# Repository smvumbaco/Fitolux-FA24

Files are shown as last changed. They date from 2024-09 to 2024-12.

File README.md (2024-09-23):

MAKE SURE TO SUBMIT A PULL REQUEST BEFORE EACH BREAKING MERGE

# <PROJECT NAME>
<ADD BLURB ABOUT PROJECT>

## Directory Structure:
```
.
|
|───production  # contains files needed for final prototype
|   |
|   |───eCAD    # contains the KiCAD project
|   └───src     # contains the code needed for deployment
|
|───testing     # contains files relevant to testing components
|
└───README.md   # this file!
```

## Preferred Tools
- KiCAD for PCB development
- Visual Studio Code / PlatformIO for code development
- Git CLI / GitHub Desktop for managing Git

## Branches
> To isolate conflicts for schematics and code, we use two branches to actually develop off of depending on discipline
- `develop/ecad` is for schematic development, please create PR's into this branch for schematics and operate in this branch for layout
- `develop/src` is for code development, please create PR's into this branch for features

## References
- Schematics + Components (WIP)

## Practice Good Git Hygiene!
1. Only commit files you intended to change
2. Create branches for each feature, and larger branches for each development effort (i.e. ```develop/*```)
3. Check your branch before starting work
4. Pull frequently to avoid conflicts
5. Make Pull Requests when you are ready to merge into a larger branch

## Git Resources

* [Setting up Git](https://fanatical-colossus-434.notion.site/Git-Installation-and-Setup-d07b7d1ab5544424876f9fd3b4a0b312)
* [Intro to Git Crash Course](https://fanatical-colossus-434.notion.site/Crash-Course-Intro-to-Git-809641611da9478b8f9cca8fd97e49fe)

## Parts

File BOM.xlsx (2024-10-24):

Component | Package size | Value with unit | Link (JLCPCB)
Resistor | 403 | 10 ohms | Example

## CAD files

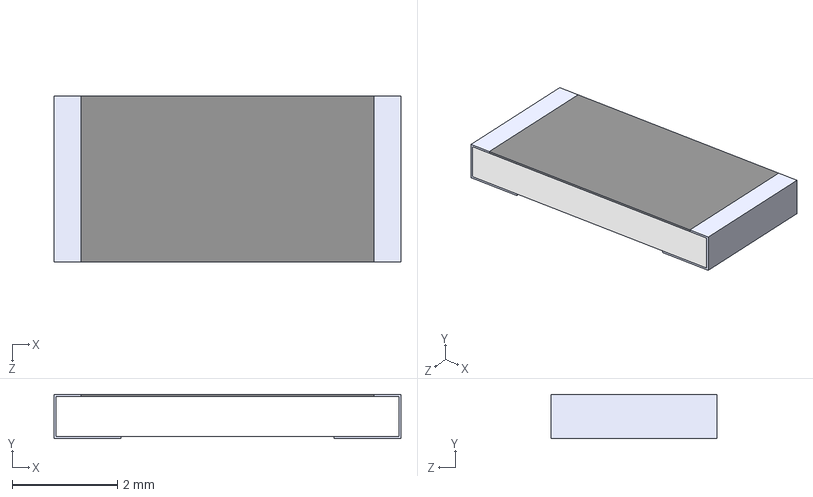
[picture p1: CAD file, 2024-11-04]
production/ecad/components/cad/R2_30k.step
6.58 x 0.84 x 3.15 mm

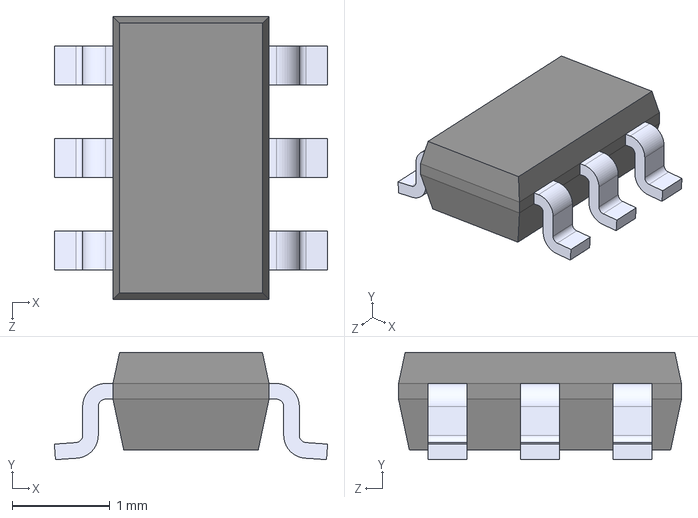
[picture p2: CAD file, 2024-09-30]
production/ecad/components/cad/TPS56339DDCR.step
2.80 x 1.10 x 2.90 mm

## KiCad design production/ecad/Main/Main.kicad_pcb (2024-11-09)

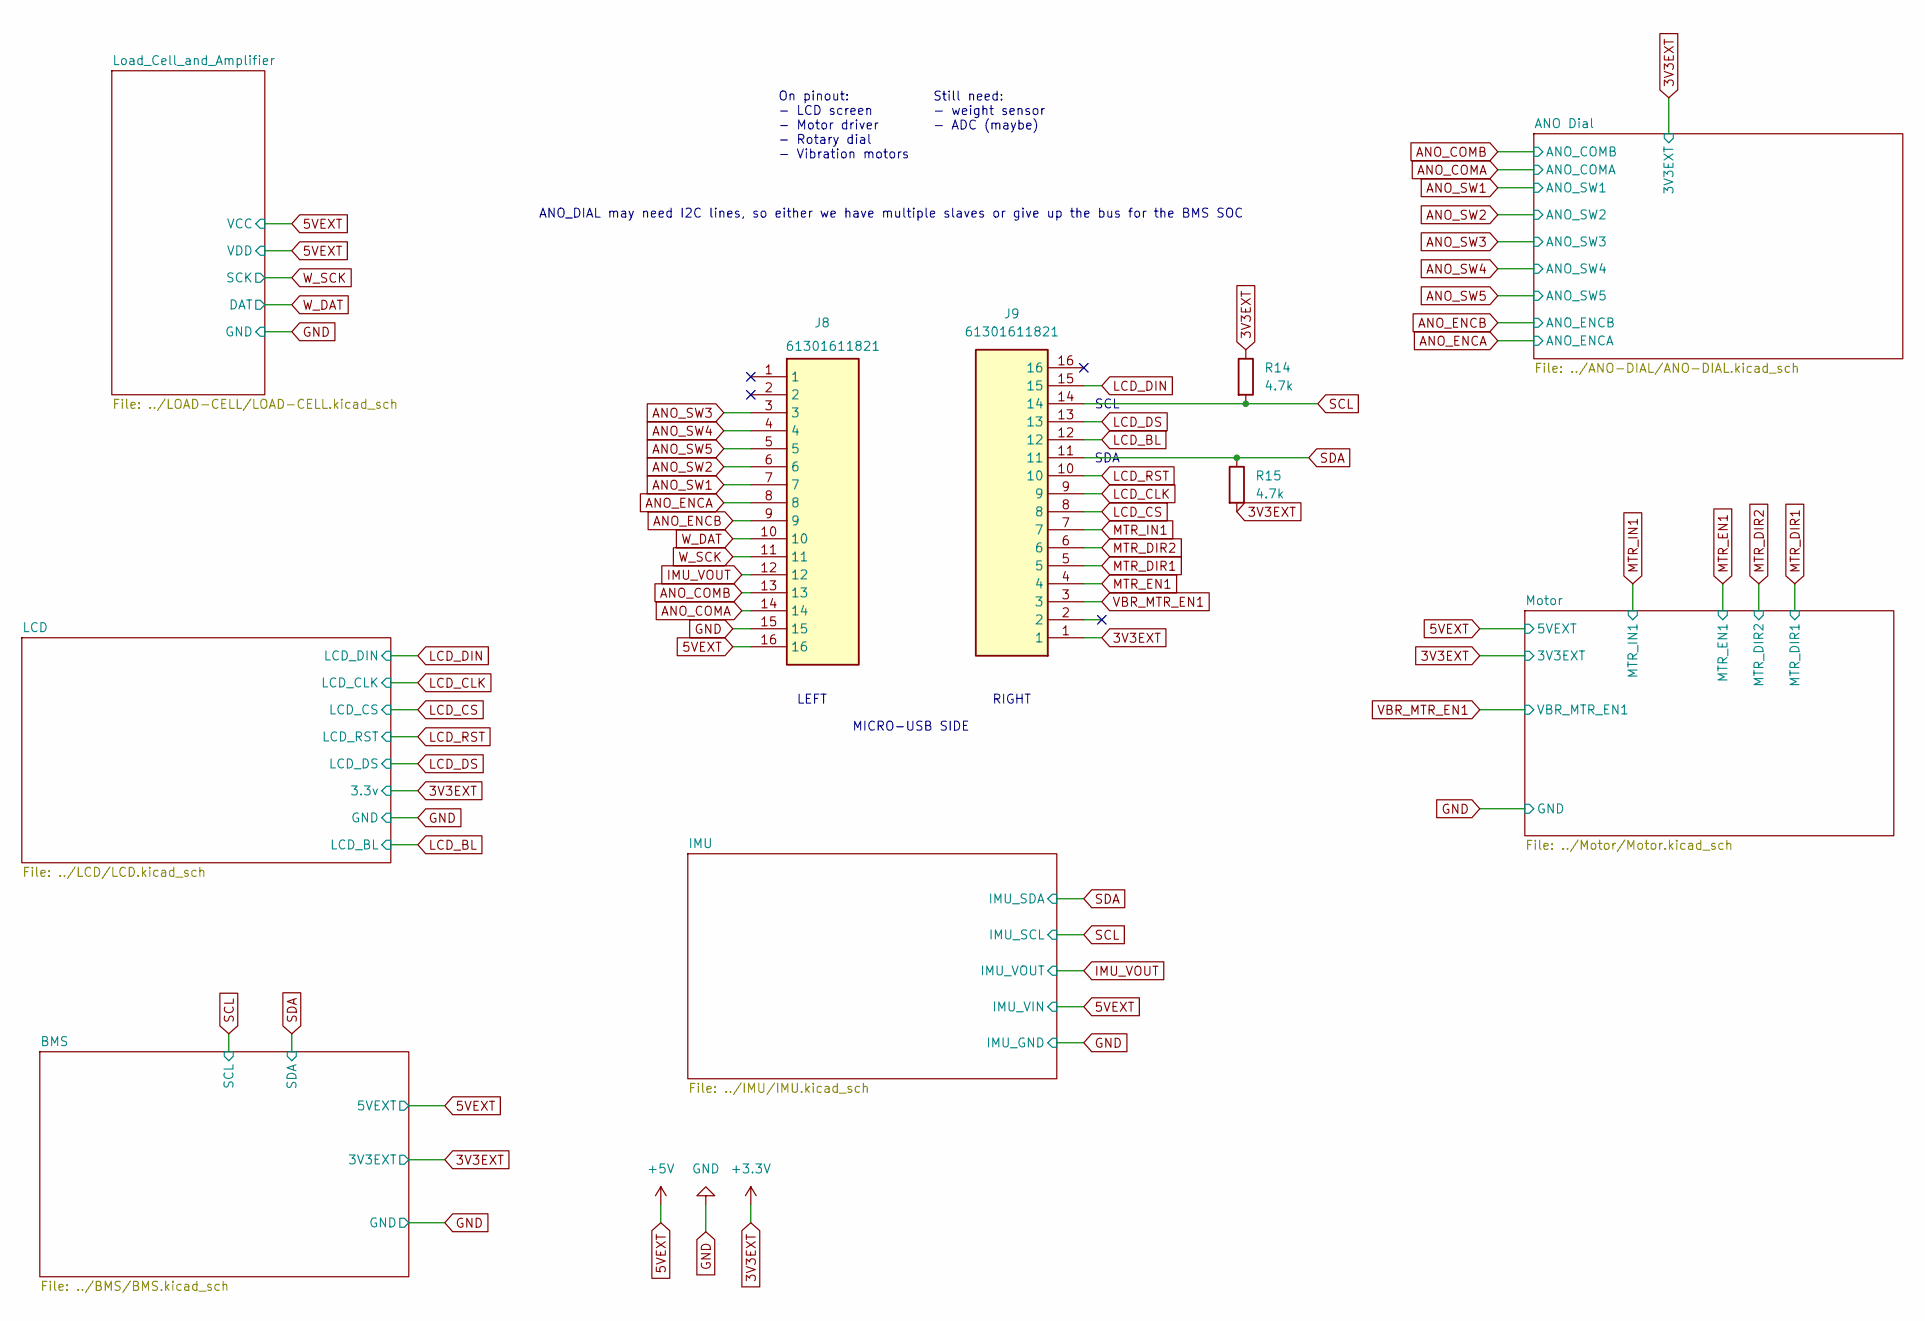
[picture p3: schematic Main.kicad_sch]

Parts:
J8, J9: 61301611821; 15posheader; Manufacturer_Part_Number 61301611821; Mouser Part Number 710-61301611821
R14, R15: 4.7k; R_0603_1608Metric_Pad0.98x0.95mm_HandSolder

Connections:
3V3EXT: J9.1, R14.1, R15.2; also elsewhere on the board
5VEXT: J8.16; also elsewhere on the board
ANO_COMA: J8.14; also elsewhere on the board
ANO_COMB: J8.13
ANO_ENCA: J8.8; also elsewhere on the board
ANO_ENCB: J8.9; also elsewhere on the board
ANO_SW1: J8.7; also elsewhere on the board
ANO_SW2: J8.6; also elsewhere on the board
ANO_SW3: J8.3; also elsewhere on the board
ANO_SW4: J8.4; also elsewhere on the board
ANO_SW5: J8.5; also elsewhere on the board
GND: J8.15; also elsewhere on the board
IMU_VOUT: J8.12; also elsewhere on the board
LCD_BL: J9.12; also elsewhere on the board
LCD_CLK: J9.9; also elsewhere on the board
LCD_CS: J9.8; also elsewhere on the board
LCD_DIN: J9.15; also elsewhere on the board
LCD_DS: J9.13; also elsewhere on the board
LCD_RST: J9.10; also elsewhere on the board
MTR_DIR1: J9.5; also elsewhere on the board
MTR_DIR2: J9.6; also elsewhere on the board
MTR_EN1: J9.4; also elsewhere on the board
MTR_IN1: J9.7; also elsewhere on the board
SCL: J9.14, R14.2; also elsewhere on the board
SDA: J9.11, R15.1; also elsewhere on the board
VBR_MTR_EN1: J9.3; also elsewhere on the board
W_DAT: J8.10; also elsewhere on the board
W_SCK: J8.11; also elsewhere on the board

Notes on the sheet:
LEFT
Still need: - weight sensor - ADC (maybe)
SDA
MICRO-USB SIDE
RIGHT
ANO_DIAL may need I2C lines, so either we have multiple slaves or give up the bus for the BMS SOC
SCL
On pinout: - LCD screen - Motor driver - Rotary dial - Vibration motors

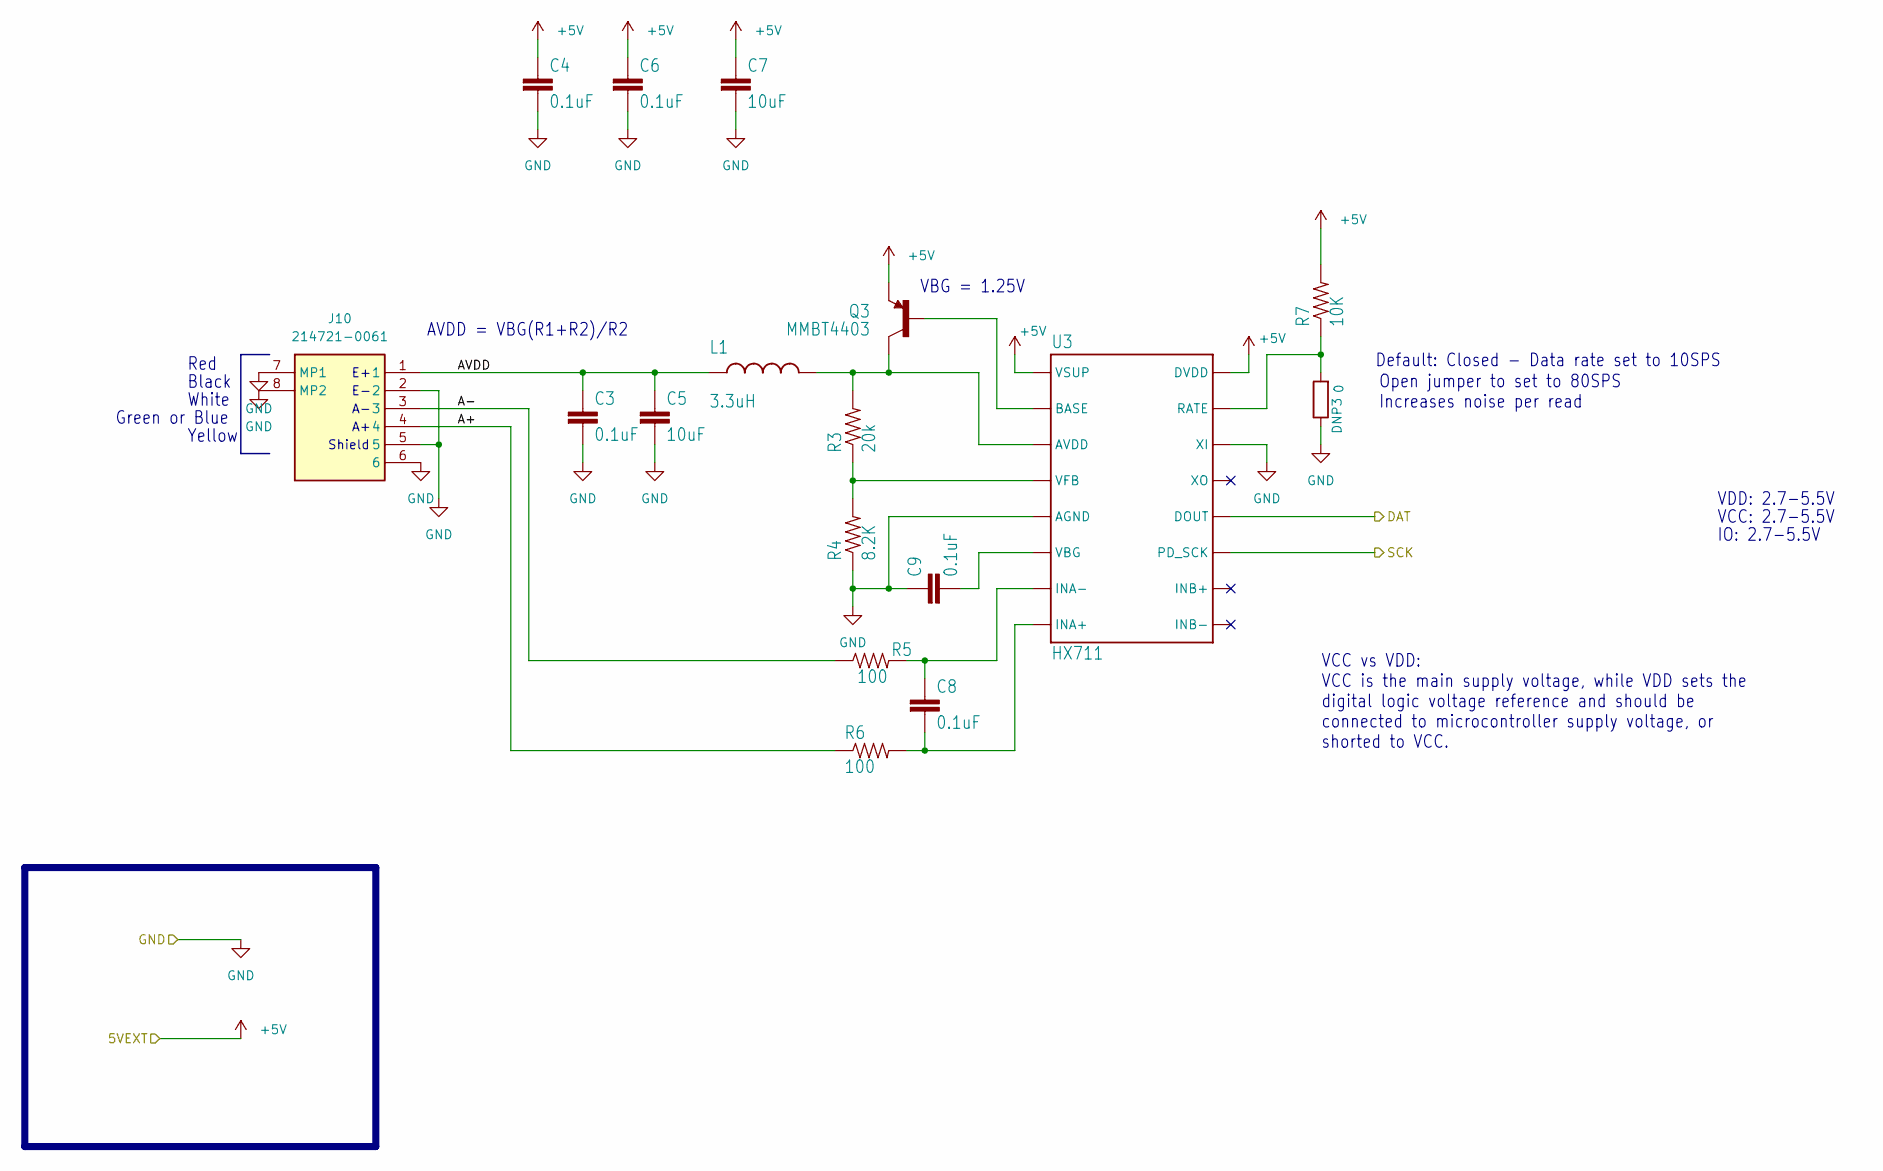
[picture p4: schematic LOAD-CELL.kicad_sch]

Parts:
C3, C4, C6, C8, C9: 0.1uF; C_0603_1608Metric
C5, C7: 10uF; C_0603_1608Metric
DNP3: 0; R_0603_1608Metric
J10: 214721-0061; 6_pos_connector; Manufacturer_Part_Number 214721-0061
L1: 3.3uH; L_0805_2012Metric
Q3: MMBT4403; mmbt4403
R3: 20k
R4: 8.2K; 8p2k
R5, R6: 100; 100ohm
R7: 10K; 10k
U3: HX711

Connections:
5VEXT: C4.1, C6.1, C7.1, Q3.2 (E), R7.2, U3.1 (VSUP), U3.16 (DVDD); also elsewhere on the board
/Load_Cell_and_Amplifier/A+: J10.4, R6.1
/Load_Cell_and_Amplifier/A-: J10.3, R5.1
/Load_Cell_and_Amplifier/AVDD: C3.1, C5.1, J10.1, L1.1
GND: C3.2, C4.2, C5.2, C6.2, C7.2, C9.1, DNP3.1, J10.2, J10.5, J10.6, J10.7 (MP1), J10.8 (MP2), R4.1, U3.5 (AGND), U3.14 (XI); also elsewhere on the board
unnamed: Q3.1 (B), U3.2 (BASE)
unnamed: L1.2, Q3.3 (C), R3.2, U3.3 (AVDD)
unnamed: C8.2, R6.2, U3.8 (INA+)
unnamed: C8.1, R5.2, U3.7 (INA-)
unnamed: DNP3.2, R7.1, U3.15 (RATE)
unnamed: C9.2, U3.6 (VBG)
unnamed: R3.1, R4.2, U3.4 (VFB)
W_DAT: U3.12 (DOUT); also elsewhere on the board
W_SCK: U3.11 (PD_SCK); also elsewhere on the board

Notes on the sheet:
Green or Blue
Shield
VCC vs VDD: VCC is the main supply voltage, while VDD sets the digital logic voltage reference and should be connected to microcontroller supply voltage, or shorted to VCC.
Open jumper to set to 80SPS Increases noise per read
Yellow
VDD: 2.7-5.5V
Red
VCC: 2.7-5.5V
Default: Closed - Data rate set to 10SPS
Black
AVDD = VBG(R1+R2)/R2
IO: 2.7-5.5V
White
VBG = 1.25V

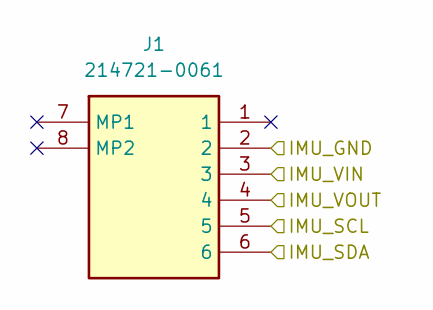
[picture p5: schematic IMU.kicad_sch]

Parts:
J1: 214721-0061; 2147210061; Manufacturer_Part_Number 214721-0061

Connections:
5VEXT: J1.3; also elsewhere on the board
GND: J1.2, J1.7 (MP1), J1.8 (MP2); also elsewhere on the board
IMU_VOUT: J1.4; also elsewhere on the board
SCL: J1.5; also elsewhere on the board
SDA: J1.6; also elsewhere on the board

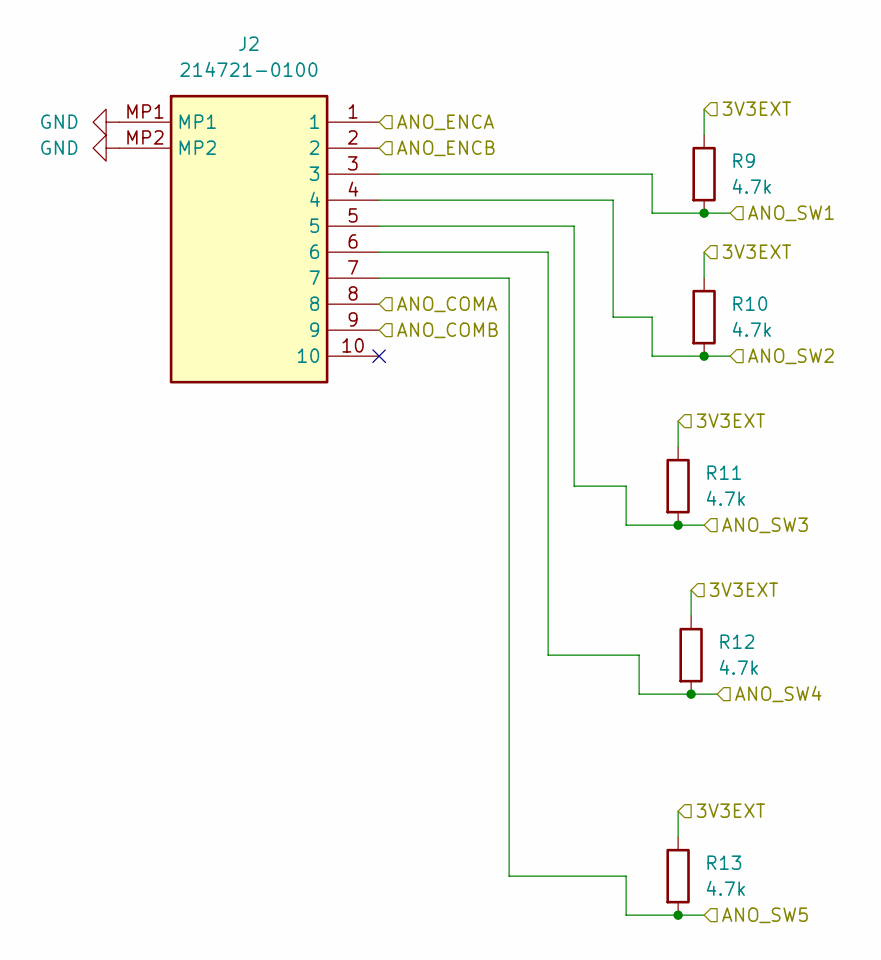
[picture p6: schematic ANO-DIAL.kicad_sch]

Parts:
J2: 214721-0100; 8positionheader; Mouser Part Number 538-214721-0100
R9, R10, R11, R12, R13: 4.7k; R_0603_1608Metric

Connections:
3V3EXT: R9.1, R10.1, R11.1, R12.1, R13.1; also elsewhere on the board
ANO_COMA: J2.8; also elsewhere on the board
ANO_ENCA: J2.1; also elsewhere on the board
ANO_ENCB: J2.2; also elsewhere on the board
ANO_SW1: J2.3, R9.2; also elsewhere on the board
ANO_SW2: J2.4, R10.2; also elsewhere on the board
ANO_SW3: J2.5, R11.2; also elsewhere on the board
ANO_SW4: J2.6, R12.2; also elsewhere on the board
ANO_SW5: J2.7, R13.2; also elsewhere on the board
GND: J2.MP1, J2.MP2; also elsewhere on the board

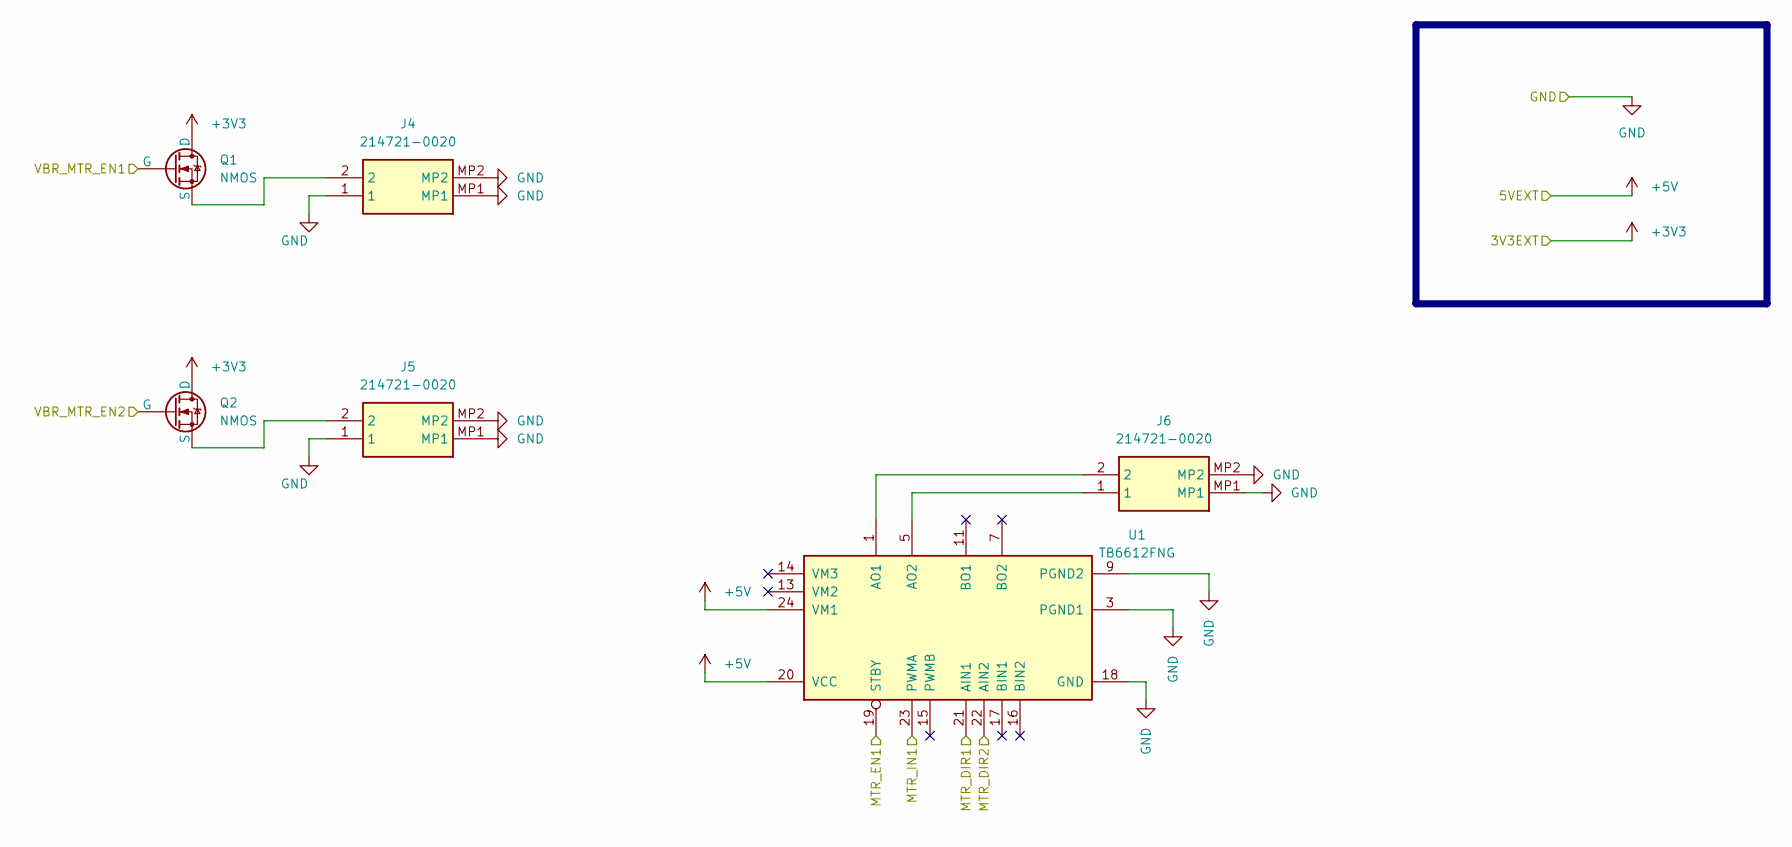
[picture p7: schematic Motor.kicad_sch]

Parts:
J4, J5, J6: 214721-0020; 2positionheader; Mouser Part Number 538-214721-0020
Q1, Q2: NMOS; SOT50P160X90-3N
U1: TB6612FNG; SSOP-24_5.3x8.2mm_P0.65mm

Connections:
3V3EXT: Q1.1 (D), Q2.1 (D); also elsewhere on the board
5VEXT: U1.20 (VCC), U1.24 (VM1); also elsewhere on the board
GND: J4.1, J4.MP1, J4.MP2, J5.1, J5.MP1, J5.MP2, J6.MP1, J6.MP2, U1.3 (PGND1), U1.4 (PGND1), U1.9 (PGND2), U1.10 (PGND2), U1.18 (GND); also elsewhere on the board
MTR_DIR1: U1.21 (AIN1); also elsewhere on the board
MTR_DIR2: U1.22 (AIN2); also elsewhere on the board
MTR_EN1: U1.19 (STBY); also elsewhere on the board
MTR_IN1: U1.23 (PWMA); also elsewhere on the board
unnamed: J6.1, U1.5 (AO2), U1.6 (AO2)
unnamed: J6.2, U1.1 (AO1), U1.2 (AO1)
unnamed: J4.2, Q1.3 (S)
unnamed: J5.2, Q2.3 (S)
VBR_MTR_EN1: Q1.2 (G), Q2.2 (G); also elsewhere on the board

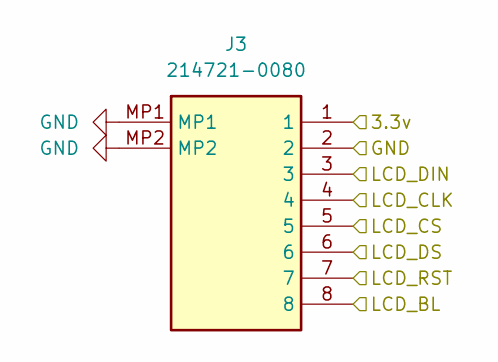
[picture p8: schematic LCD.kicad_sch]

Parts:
J3: 214721-0080; 8positionheader; Manufacturer_Part_Number 214721-0080

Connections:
3V3EXT: J3.1; also elsewhere on the board
GND: J3.2, J3.MP1, J3.MP2; also elsewhere on the board
LCD_BL: J3.8; also elsewhere on the board
LCD_CLK: J3.4; also elsewhere on the board
LCD_CS: J3.5; also elsewhere on the board
LCD_DIN: J3.3; also elsewhere on the board
LCD_DS: J3.6; also elsewhere on the board
LCD_RST: J3.7; also elsewhere on the board

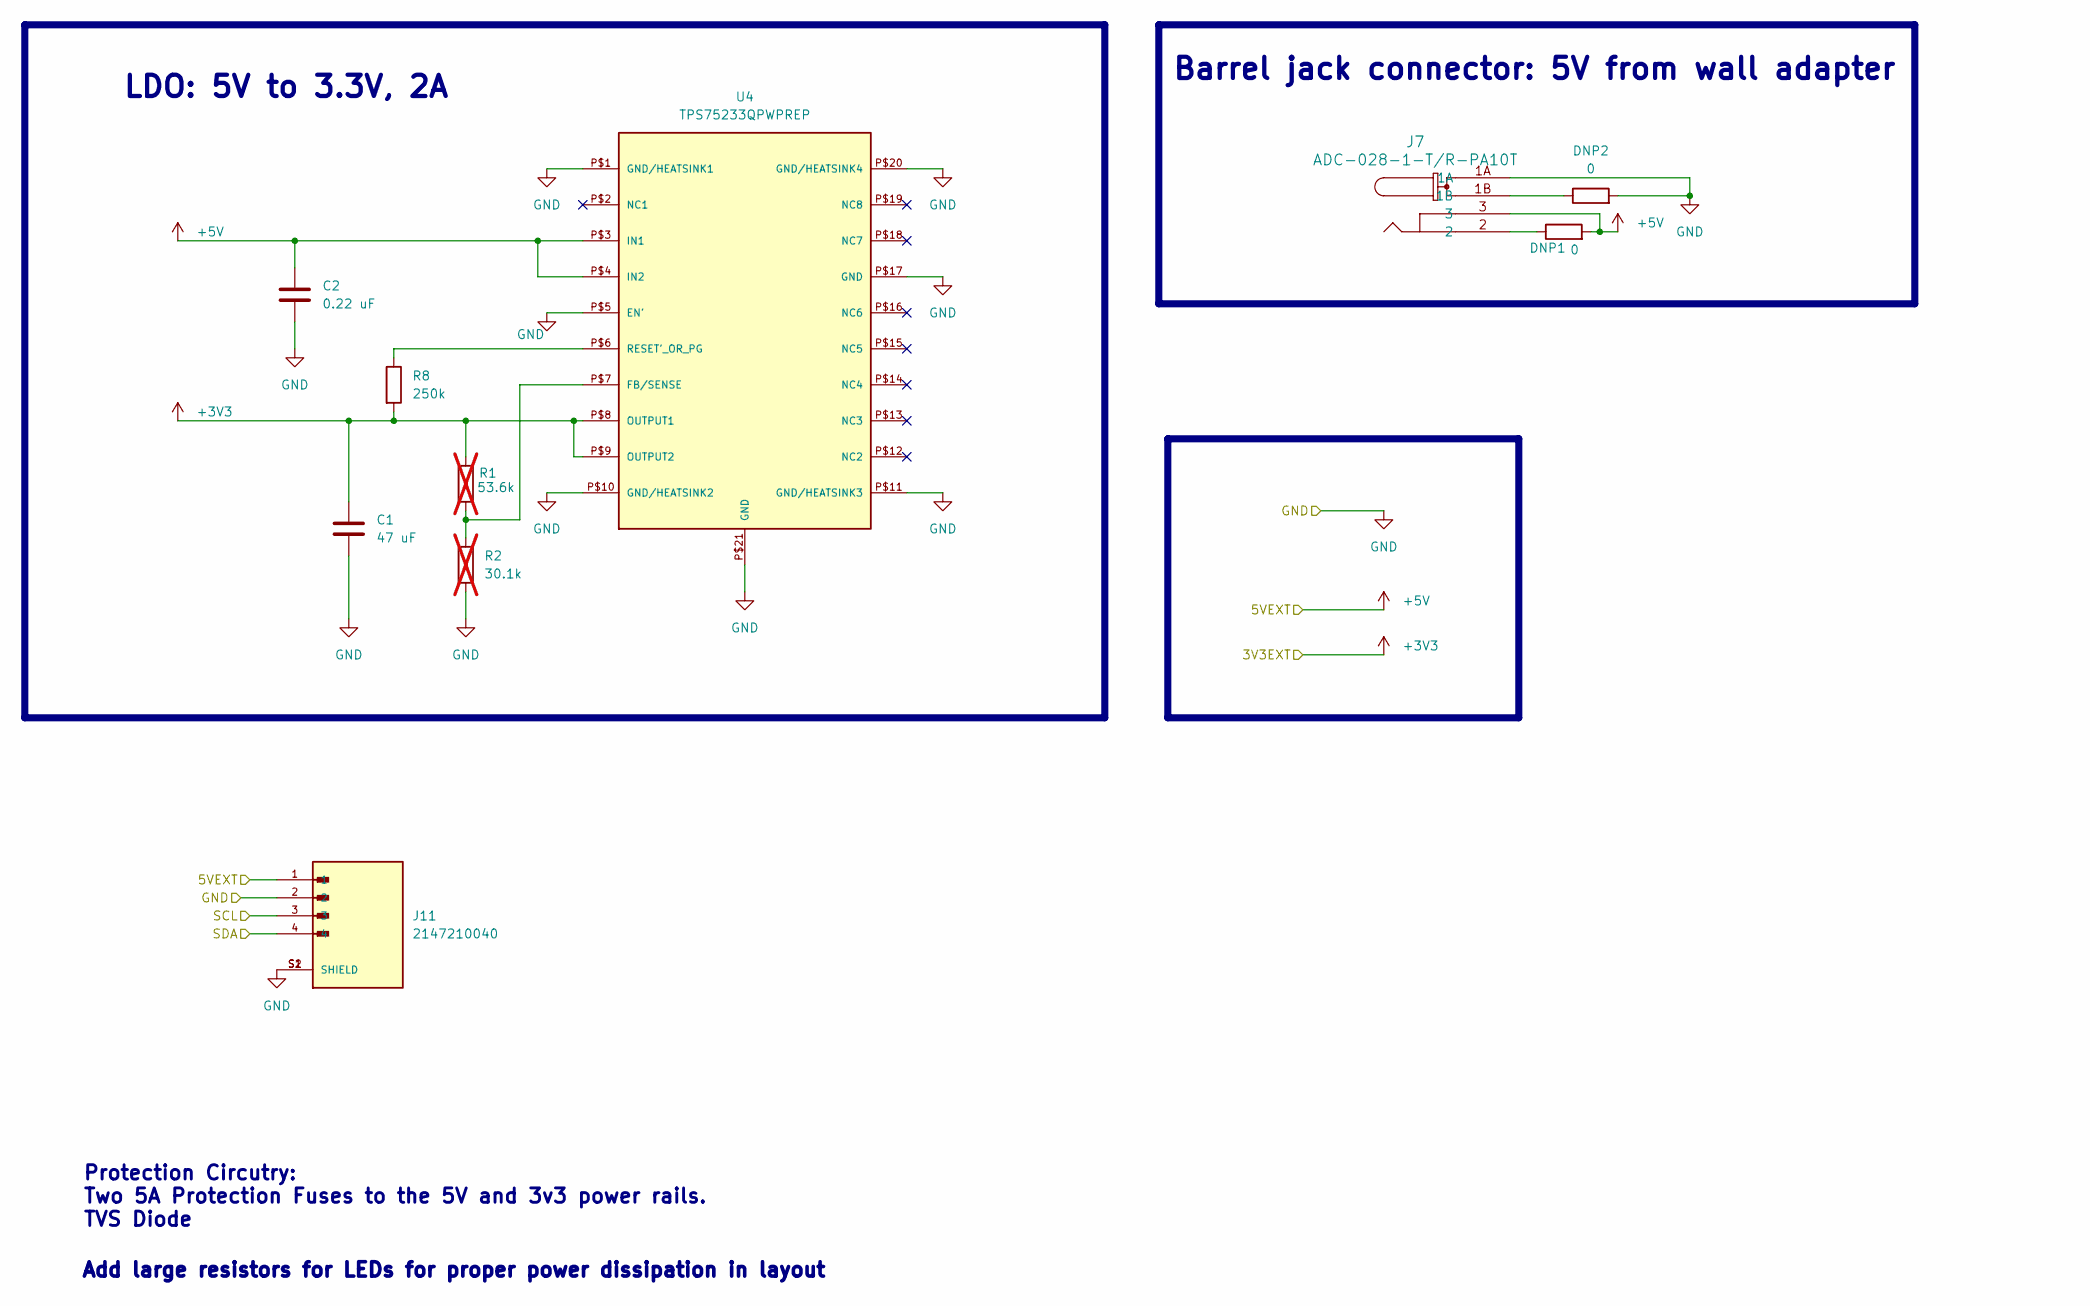
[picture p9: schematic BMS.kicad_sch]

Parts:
C1: 47 uF; C_0805_2012Metric
C2: 0.22 uF; C_0603_1608Metric
DNP1, DNP2: 0; R_0603_1608Metric
J7: ADC-028-1-T/R-PA10T; ADC-028-x-T&slash_R-PA10T_ADM
J11: 2147210040; 4positionheader; PARTREV A; DigiKey_Part_Number 900-2147210040CT-ND
R1: 53.6k; R_0603_1608Metric; not fitted
R2: 30.1k; R_0603_1608Metric; not fitted
R8: 250k; R_0603_1608Metric
U4: TPS75233QPWPREP

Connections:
3V3EXT: C1.1, R1.1, R8.2, U4.P$8 (OUTPUT1), U4.P$9 (OUTPUT2); also elsewhere on the board
5VEXT: C2.1, DNP1.2, J7.3, J11.1, U4.P$3 (IN1), U4.P$4 (IN2); also elsewhere on the board
GND: C1.2, C2.2, DNP2.2, J7.1A, J11.2, J11.S1 (SHIELD), J11.S2 (SHIELD), R2.2, U4.P$1 (GND/HEATSINK1), U4.P$5 (EN'), U4.P$10 (GND/HEATSINK2), U4.P$11 (GND/HEATSINK3), U4.P$17 (GND), U4.P$20 (GND/HEATSINK4), U4.P$21 (GND); also elsewhere on the board
unnamed: DNP1.1, J7.2
unnamed: DNP2.1, J7.1B
unnamed: R1.2, R2.1, U4.P$7 (FB/SENSE)
unnamed: R8.1, U4.P$6 (RESET'_OR_PG)
SCL: J11.3; also elsewhere on the board
SDA: J11.4; also elsewhere on the board

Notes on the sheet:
Barrel jack connector: 5V from wall adapter
LDO: 5V to 3.3V, 2A
Add large resistors for LEDs for proper power dissipation in layout
Protection Circutry: Two 5A Protection Fuses to the 5V and 3v3 power rails. TVS Diode

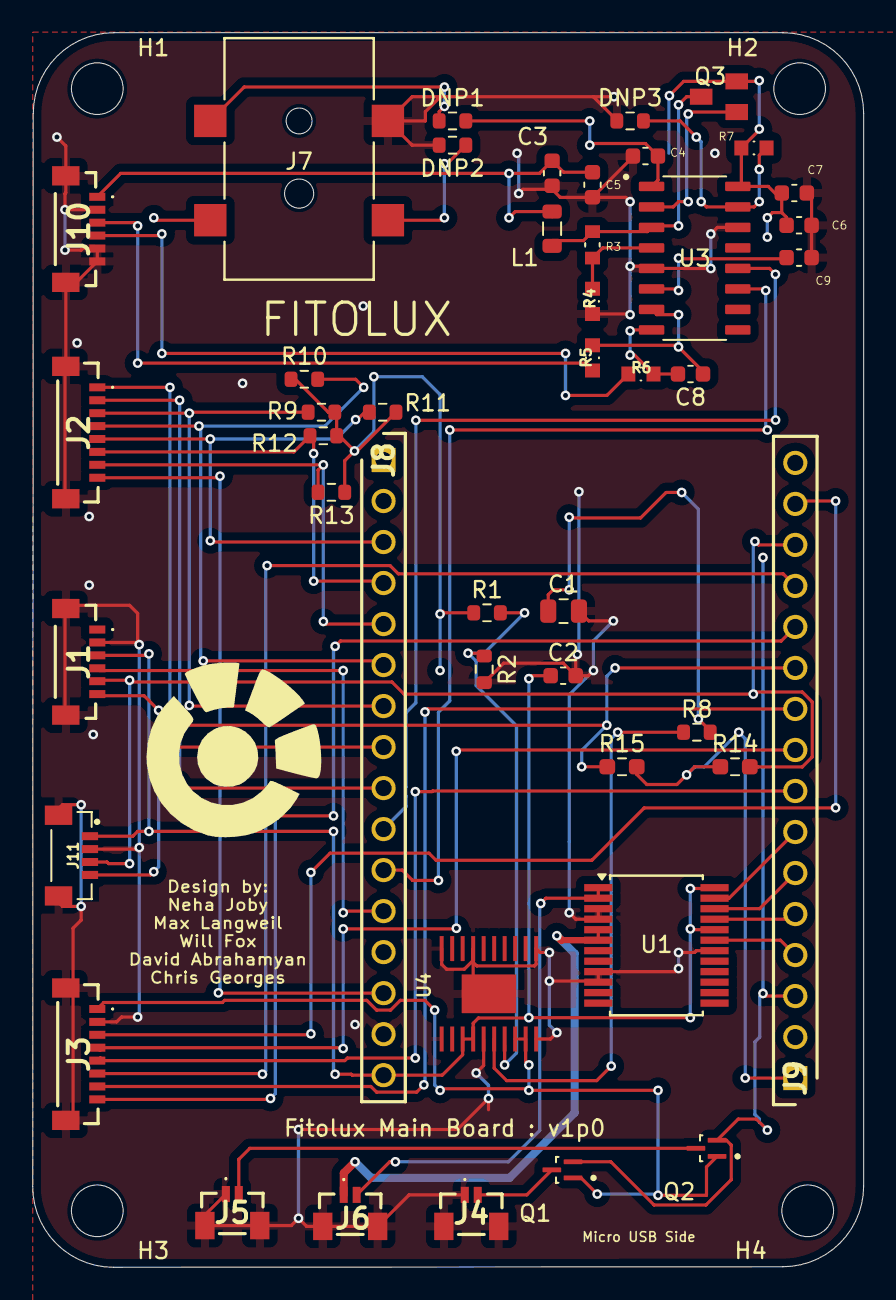
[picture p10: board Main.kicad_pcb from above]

Board: 4 copper layers, 51.5 x 76.5 mm, 49 parts (0 on the bottom side), 45 nets.

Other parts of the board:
H1, H2, H3, H4: MountingHole; MountingHole_3.2mm_M3_ISO7380

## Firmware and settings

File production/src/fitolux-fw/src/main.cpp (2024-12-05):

// ----------- PORTABLE CODE ----------- 

#include <Arduino.h>
#include <SPI.h>
#include <TFT_eSPI.h>
#include "AnoDial.h"
#include <RotaryEncoder.h>
#include "driver/i2c.h"
// #include "max17048.h"
// include screen display headers
#include "PortScreenComplete.h"
#include "PortScreenDispensing.h"
#include "PortScreenHome.h"
#include "MotorController.h"
#include "LoadCell.h"
#include "Adafruit_MAX1704X.h"


int weightSelectGrams;

TFT_eSPI tft = TFT_eSPI(TFT_WIDTH, TFT_HEIGHT);  // Create display object
AnoDial ano;
MotorController augerMotor;
LoadCell loadCell;
Adafruit_MAX17048 fuelGuage;


enum State {
    OFF,
    START,
    HOME_SCREEN,
    ADJUST_WEIGHT,
    DISPENSING,
    COMPLETE
};

static State currentState = START;

int batteryLevel;

void setup() {
  // set up serial com
  Serial.begin(115200);
  Serial.println("Begin");
  

  // init TFT screen
  // tft.init();             // Initialize the display
  // tft.setRotation(2);     // Set rotation (adjust as necessary)
  
  // digitalWrite(TFT_BL, HIGH);

  // tft.fillScreen(TFT_BROWN); // Background color

  // displayHomeScreen(tft);

  // calibration factor for weight sensor
  loadCell.setCalibration(3648000);


  // Initialize I2C communication
  if (!fuelGuage.begin()) {
    Serial.println("Could not find MAX17048 chip, check wiring!");
    while (1);
  }

  Serial.println("MAX17048 found!");
  
}

void loop() {

  // if power switch is off
  // if (digitalRead(POWER_SWITCH_PIN) == HIGH) {
  //     currentState = OFF;
  //     return;
  // } else if (currentState == OFF) {
  //     currentState = START;
  // }
  switch (currentState) {
      case START:
        // displayPortHomeScreen(tft);
        Serial.println("CURRENT STATE: START");
        delay(1000);
        currentState = HOME_SCREEN;
        Serial.println("Current State: HOME");
        batteryLevel = fuelGuage.cellPercent();
        // displayPortHomeScreen(tft);
        // tft.drawString("HS", 45, 80, 2);
        break;
      case HOME_SCREEN:
        // displayHomeScreen(tft);
        batteryLevel = fuelGuage.cellPercent();
        // Serial.println("SOC: ");
        // Serial.println(batteryLevel);
        delay(50);
        if (ano.getButtonPress(ano.CENTER))
        {
          currentState = ADJUST_WEIGHT;
          // tft.drawString("AW", 45, 80, 2);
        }
        Serial.println("CURRENT STATE: ADJUST WEIGHT");
        // break;
      case ADJUST_WEIGHT:
        // Serial.println("ADJUST WEIGHT");
        ano.checkEncoder();
        // // int newPosition = dial.getPosition();
        // if (newPosition > 0 && selectedWeight < 100) {
        //     selectedWeight++;
        //     dial.setPosition(0);
        //     updateWeightDisplay(selectedWeight);
        // } else if (newPosition < 0 && selectedWeight > 1) {
        //     selectedWeight--;
        //     dial.setPosition(0);
        //     updateWeightDisplay(selectedWeight);
        // }
        // if (digitalRead(DIAL_BUTTON_PIN) == LOW) {
        //     while (digitalRead(DIAL_BUTTON_PIN) == LOW);
        //     currentState = DISPENSING;
        // }
        if (ano.last_rotary != ano.curr_rotary)
        {
          weightSelectGrams = ano.curr_rotary;
          updateValue(tft, weightSelectGrams, batteryLevel);
          // Serial.print("Weight Select: ");
          // Serial.println(weightSelectGrams);
          
          tft.drawNumber(weightSelectGrams, 45, 100, 2);
        }
        // displayHomeScreen(tft);
        if (ano.getButtonPress(ano.RIGHT))
        {
          Serial.println("RIGHT");
          weightSelectGrams += 1;
          tft.drawNumber(weightSelectGrams, 45, 100, 2);
        }
        if (ano.getButtonPress(ano.LEFT))
        {
          Serial.println("LEFT");
        }
        if (ano.getButtonPress(ano.UP))
        {
          Serial.println("UP");
          tft.drawNumber(weightSelectGrams, 45, 100, 2);
        }
        if (ano.getButtonPress(ano.DOWN))
        {
          Serial.println("DOWN");
        }
        if (ano.getButtonPress(ano.CENTER))
        {
          currentState = DISPENSING;
          tft.drawString("D", 45, 80, 2);
        }
        break;
      case DISPENSING:
        displayDispensingScreen(tft);

        // if last state wasn't dispensing
          // set motor pins low / disable motors
          // tare loadCell (loadCell.begin())

        // if ()
        // loadCell.begin();

        // if motors off, turn vibration and stepper motors on
        if (augerMotor.getState() == 0)
        {
          augerMotor.setDirection(0);
          augerMotor.setSpeed(50);
          augerMotor.enable();
        }
        // if weightFromLoadCell >= DesiredWeight (weightSelectGrams), turn motors off (STOP DISPENSING)
        if (loadCell.readWeight() >= weightSelectGrams)
        {
          augerMotor.disable();
        }
        currentState = COMPLETE;
        // if time >= TIME_LIMIT seconds, stop
        currentState = COMPLETE;

        // TurnMotorOn();
        // SetMotorSpeed(50);
        // delay(5000);
        // TurnMotorOff();

        delay(3000);

        break;
      case COMPLETE:
        displayPortCompleteScreen(tft);
        
        if(ano.getButtonPress(ano.CENTER))
        {
          currentState = START;
        }

      case OFF:
        break;
  }


}

// // put function definitions here:
// int myFunction(int x, int y) {
//   // return x + y;
// }






// ----------- COUNTERTOP CODE ----------- 




























// #include <Arduino.h>
// #include <SPI.h>
// #include <TFT_eSPI.h>
// #include "AnoDial.h"
// #include <RotaryEncoder.h>
// #include "driver/i2c.h"
// int weightSelectGrams;
// TFT_eSPI tft = TFT_eSPI(TFT_WIDTH, TFT_HEIGHT);  // Create display object
// AnoDial ano;
// void setup() {
//   // set up serial com
//   Serial.begin(115000);
//   Serial.println("THIS. IS. FITOLUX.");
//   Serial.print("MOSI: ");
//   Serial.println(TFT_MOSI);
//   // // init TFT screen
//   // tft.init();             // Initialize the display
//   // tft.setRotation(1);     // Set rotation (adjust as necessary)
//   // tft.fillScreen(TFT_BLUE);  // Clear screen to black
  
// }
// void loop() {
//   ano.checkEncoder();
//   if (ano.getButtonPress(ano.LEFT))
//   {
//     Serial.println("left button clicked");
//     // tft.fillScreen(TFT_GREEN);  // Clear screen to black
//     // tft.setTextColor(TFT_BLACK);  // White text on a black background
//     // tft.drawNumber(weightSelectGrams, 50, 50, 4);
//   }
//   if (ano.getButtonPress(ano.RIGHT))
//   {
//     Serial.println("right button clicked");
//     // tft.fillScreen(TFT_YELLOW);  // Clear screen to black
//     // tft.setTextColor(TFT_BLACK);  // White text on a black background
//     // tft.drawNumber(weightSelectGrams, 50, 50, 4);
//   }
//   if (ano.getButtonPress(ano.UP))
//   {
//     Serial.println("up button clicked");
//     // tft.fillScreen(TFT_PURPLE);  // Clear screen to black
//     // tft.setTextColor(TFT_BLACK);  // White text on a black background
//     // tft.drawNumber(weightSelectGrams, 50, 50, 4);
//   }
//   if (ano.getButtonPress(ano.DOWN))
//   {
//     Serial.println("down button clicked");
//     // tft.fillScreen(TFT_SILVER);  // Clear screen to black
//     // tft.setTextColor(TFT_BLACK);  // White text on a black background
//     // tft.drawNumber(weightSelectGrams, 50, 50, 4);
//   }
//   if (ano.getButtonPress(ano.CENTER))
//   {
//     Serial.println("center button clicked");
//     // tft.fillScreen(TFT_GOLD);  // Clear screen to black
//     // tft.setTextColor(TFT_BLACK);  // White text on a black background
//     // tft.drawNumber(weightSelectGrams, 50, 50, 4);
//   }
// }

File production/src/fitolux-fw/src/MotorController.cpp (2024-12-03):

#include "MotorController.h"

MotorController::MotorController(){
    standbyPin = 2;
    pwmPin = 17;
    in1Pin = 4;
    in2Pin = 16;

    pinMode(standbyPin, OUTPUT);
    pinMode(pwmPin, OUTPUT);
    pinMode(in1Pin, OUTPUT);
    pinMode(in2Pin, OUTPUT);
}

void MotorController::setDirection(bool direction) {
    digitalWrite(in1Pin, !direction);
    digitalWrite(in2Pin, direction);
}

void MotorController::setSpeed(int speed) {
    analogWrite(pwmPin, speed);
}

void MotorController::enable() {
    digitalWrite(standbyPin, HIGH);
}

void MotorController::disable() {
    digitalWrite(standbyPin, LOW);
}

bool MotorController::getState() {
    if (standbyPin == HIGH) {
        return 1;
    }
    else if (standbyPin == LOW) {
        return 0;
    }
}

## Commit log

2024-09-18 blank projects
    [BMS.kicad_pcb, BMS.kicad_sch, Main.kicad_pcb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]
2024-09-28 added header pins
    [Main.kicad_sch, bootcamp.kicad_pcb, bootcamp.kicad_sch]
2024-09-30 Created BMS schematic
    [BMS.kicad_sch, TPS56339DDCR.step, power_sheet.kicad_sch]
2024-09-30 pinout first draft
    [Main.kicad_sch]
2024-09-30 added X's
    [Main.kicad_sch]
2024-09-30 test creation of heirarchical sheets
    [Main.kicad_sch, Motor.kicad_sch]
2024-10-02 added hierchal labels and added libraries
    [Main.kicad_pcb, Main.kicad_sch, Peripheral.kicad_sch]
2024-10-02 hierachel stuff
    [Main.kicad_sch, Peripheral.kicad_sch]
2024-10-07 LDO schematic is complete
    [Main.kicad_sch, Peripheral.kicad_sch, power_sheet.kicad_sch]
2024-10-09 schematic draft merged w neha
    [BMS.kicad_sch, LCD.kicad_pcb, LCD.kicad_sch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]
2024-10-14 feedback from Billayyy
    [BMS.kicad_sch, Main.kicad_sch, Motor.kicad_sch]
2024-10-15 Working on BMS schem
    [BMS.kicad_sch, LDO - RC1587M33T.step, Main.kicad_sch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]
2024-10-16 LDO symbol added to components library
    [LDO - RC1587M33T.step]
2024-10-17 Updated LDO schematic
    [BMS.kicad_sch, TPS75233QPWPREP.step]
2024-10-17 updated pullup resistors
    [BMS.kicad_sch]
2024-10-17 layout started
    [Main.kicad_pcb]
2024-10-17 erc check
    [BMS.kicad_sch, Motor.kicad_sch]
2024-10-20 LDO schematic updated
    [BMS.kicad_sch]
2024-10-20 Barrel jack added
    [BMS.kicad_sch]
2024-10-20 Barrel jack updated
    [BMS.kicad_sch]
2024-10-21 merged david and neha work
    [ANO-DIAL.kicad_pcb, ANO-DIAL.kicad_sch, BMS.kicad_sch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]
2024-10-21 Stylistic changes made
    [BMS.kicad_sch, LOAD-CELL.kicad_sch, Main.kicad_sch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]
2024-10-24 Stylistic edits made
    [BMS.kicad_sch, LOAD-CELL.kicad_sch, Main.kicad_sch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]
2024-10-24 more changes
    [LOAD-CELL.kicad_sch, Main.kicad_sch]
2024-10-24 changed pinout
    [Main.kicad_sch]
2024-10-27 reverted to Max branch from Wed and moved ANO button GPIO pins to input only
    [Main.kicad_sch]
2024-10-27 BMS fixed
    [BMS.kicad_sch, Main.kicad_sch]
2024-10-28 Made some stylistic adjustments
    [Main.kicad_sch]
2024-10-31 added imu and connector
    [BMS.kicad_sch, IMU.kicad_pcb, IMU.kicad_sch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]
2024-11-03 added connector for pisugar
    [BMS.kicad_sch, LOAD-CELL.kicad_sch, Main.kicad_sch]
2024-11-04 DNP resistors were added
    [BMS.kicad_sch, IMU.kicad_sch]
2024-11-04 Changed 53.6k resistor into two 27k resistors in series (BMS)
    [BMS.kicad_sch, LOAD-CELL.kicad_sch]
2024-11-04 All BMS footprints added to components folder
    [R2_30k.step]
2024-11-04 All footprints for components + passives from BMS are assigned and ready for layout
    [BMS.kicad_sch, LOAD-CELL.kicad_sch, Main.kicad_pcb]
2024-11-04 some changes
    [BMS.kicad_sch]
2024-11-04 NMOS motor footprints added
    [Motor.kicad_sch]
2024-11-05 david changes
    [LOAD-CELL.kicad_sch]
2024-11-05 my pushes
    [Main.kicad_pcb]
2024-11-05 Component placement complete
    [ANO-DIAL.kicad_sch, BMS.kicad_sch, IMU.kicad_sch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]
2024-11-05 GND, 5V, and 3v3 planes added
    [Main.kicad_pcb]
2024-11-05 did some routing
    [Main.kicad_pcb]
2024-11-05 more routing
    [Main.kicad_pcb]
2024-11-05 just some more routing
    [Main.kicad_pcb]
2024-11-05 my final changes
    [Main.kicad_pcb]
2024-11-05 1 last change
    [Main.kicad_pcb]
2024-11-06 schematic changes and pcb
    [ANO-DIAL.kicad_sch, BMS.kicad_sch, IMU.kicad_sch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]
2024-11-06 downsized board
    [Main.kicad_pcb]
2024-11-06 Routing updated
    [Main.kicad_pcb]
2024-11-06 Final changes updated
    [Main.kicad_pcb]
2024-11-07 Added 3V3, 5V, and GND power planes on layer 2
    [BMS.kicad_sch, Main.kicad_pcb, Main.kicad_sch]
2024-11-07 Made updates from Sean
    [Main.kicad_pcb]
2024-11-07 i2c pull ups and changes
    [Main.kicad_pcb, Main.kicad_sch]
2024-11-07 mounting holes 3.2 mm
    [Main.kicad_pcb]
2024-11-07 added GND plane
    [Main.kicad_pcb]
2024-11-07 silkscreen labels adjusted
    [Main.kicad_pcb]
2024-11-07 more silkscreen updates
    [Main.kicad_pcb]
2024-11-07 silkscreen artwork
    [Main.kicad_pcb]
2024-11-07 final changes
    [Main.kicad_pcb]
2024-11-07 resistor and inductor
    [ANO-DIAL.kicad_sch, Main.kicad_pcb]
2024-11-08 6 errors
    [LOAD-CELL.kicad_sch, Main.kicad_pcb]
2024-11-08 No more DRC errors yay!!
    [Main.kicad_pcb]
2024-11-08 some silk screen updates
    [Main.kicad_pcb]
2024-11-08 silkscreen changes
    [Main.kicad_pcb]
2024-11-08 changed fet footp
    [Main-B_Cu.gbr, Main-B_Mask.gbr, Main-B_Paste.gbr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]
2024-11-09 moved connectors
    [BMS.kicad_sch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]
2024-11-18 added load cell and motor code
